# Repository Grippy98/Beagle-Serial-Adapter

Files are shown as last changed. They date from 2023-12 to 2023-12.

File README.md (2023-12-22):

# Beagle-Serial-Adapter
A CH340E Based Minimalist USB-Serial Adapter for BeaglePlay, AI64 and More.

The board is 4 layers and features components mainly sourced from LCSC for cost effectiveness and ease of building via JLC PCB or similar. 
It is designed in KiCAD 7.0.9.

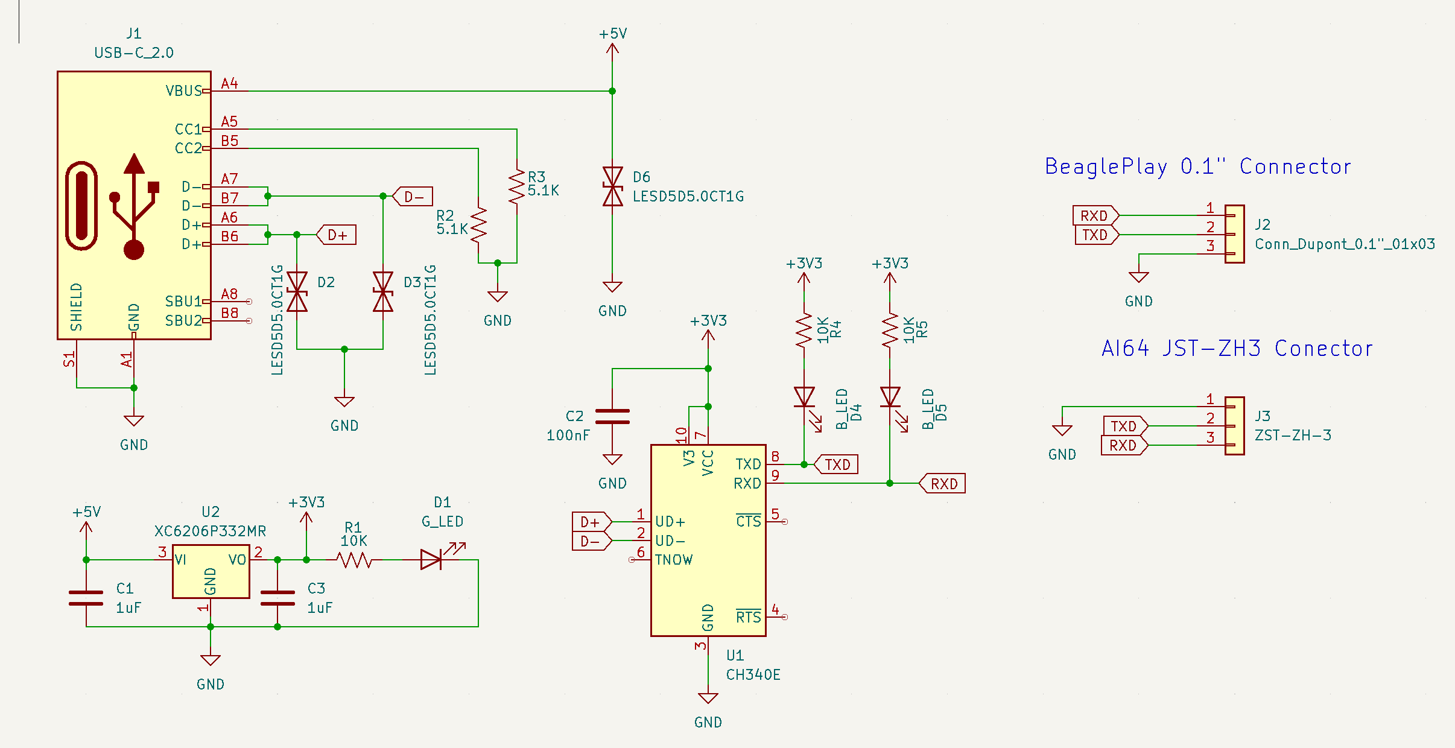
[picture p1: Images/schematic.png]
Schematic


Front           |  Back
:-------------------------:|:-------------------------:
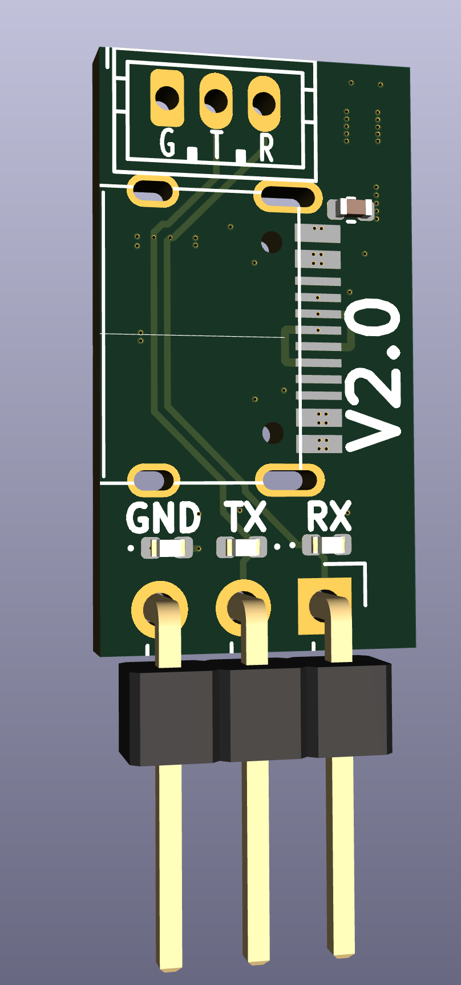
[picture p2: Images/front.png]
Front
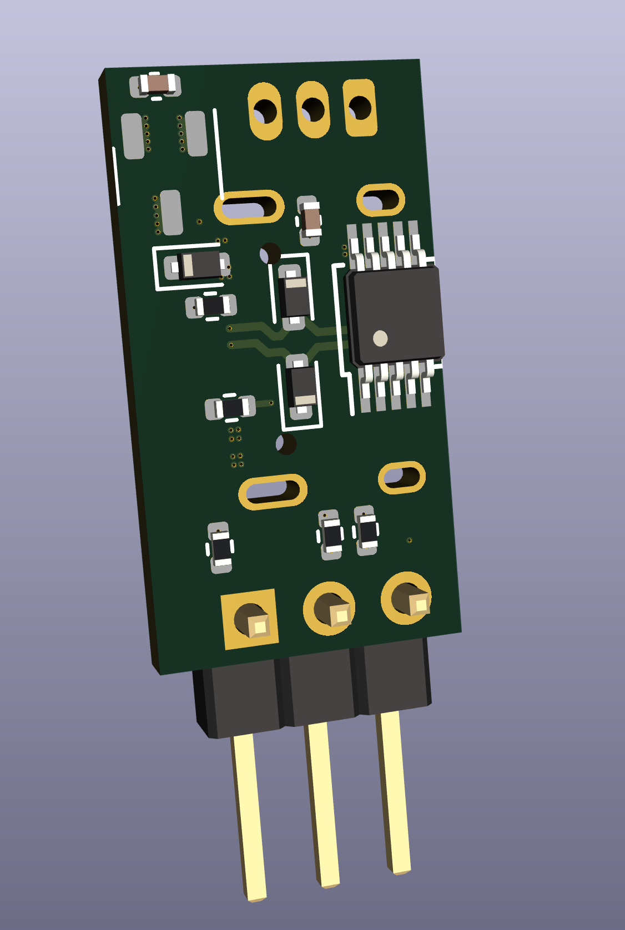
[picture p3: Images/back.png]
Back
  |  

> [!NOTE]  
> The header at the bottom should be Female to mate with BeaglePlay, not male as shown in the 3D render.

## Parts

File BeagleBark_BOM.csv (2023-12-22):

Id | Designator | Footprint | Quantity | Designation | Supplier and ref
1 | J3 | JST_ZH_B3B-ZR_1x03_P1.50mm_Vertical | 1 | ZST-ZH-3
2 | D1 | LED_0402_1005Metric | 1 | G_LED
3 | J2 | PinHeader_1x03_P2.54mm_Horizontal | 1 | Conn_Dupont_0.1_01x03"
4 | J1 | TYPE-C-31-M-12 | 1 | USB-C_2.0
5 | D5,D4 | LED_0402_1005Metric | 2 | B_LED
6 | C1,C3 | C_0402_1005Metric | 2 | 1uF
7 | U2 | SOT-23-3 | 1 | XC6206P332MR
8 | R2,R3 | R_0402_1005Metric | 2 | 5.1K
9 | R5,R4,R1 | R_0402_1005Metric | 3 | 10K
10 | D3,D2,D6 | D_SOD-523 | 3 | LESD5D5.0CT1G
11 | U1 | MSOP-10_3x3mm_P0.5mm | 1 | CH340E
12 | C2 | C_0402_1005Metric | 1 | 100nF

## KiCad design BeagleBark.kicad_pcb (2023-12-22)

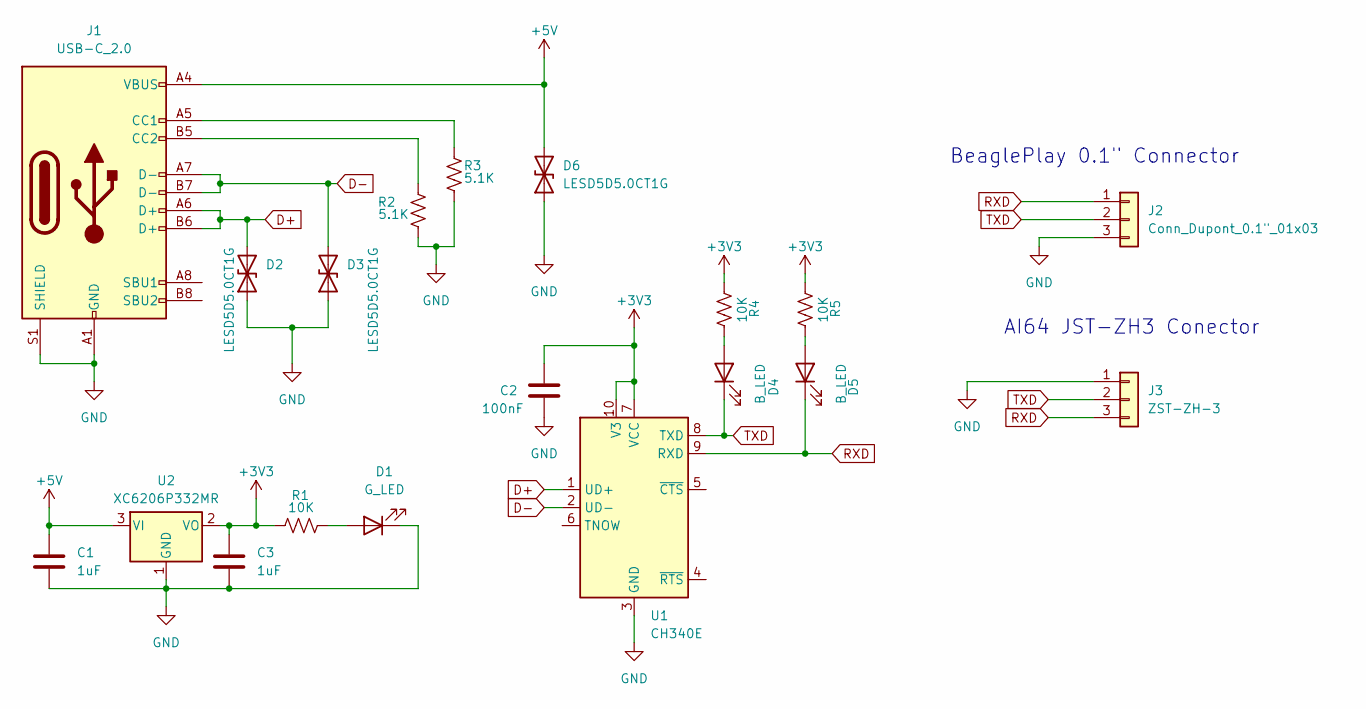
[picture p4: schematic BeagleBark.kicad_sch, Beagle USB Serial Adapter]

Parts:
C1, C3: 1uF; C_0402_1005Metric
C2: 100nF; C_0402_1005Metric
D1: G_LED; LED_0402_1005Metric
D2, D3, D6: LESD5D5.0CT1G; D_SOD-523
D4, D5: B_LED; LED_0402_1005Metric
J1: USB-C_2.0; TYPE-C-31-M-12
J2: Conn_Dupont_0.1"_01x03; PinHeader_1x03_P2.54mm_Horizontal
J3: ZST-ZH-3; JST_ZH_B3B-ZR_1x03_P1.50mm_Vertical
R1, R4, R5: 10K; R_0402_1005Metric
R2, R3: 5.1K; R_0402_1005Metric
U1: CH340E; MSOP-10_3x3mm_P0.5mm
U2: XC6206P332MR; SOT-23-3

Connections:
+3V3: C2.1, C3.1, R1.1, R4.1, R5.1, U1.7 (VCC), U1.10 (V3), U2.2 (VO)
+5V: C1.1, D6.2 (A2), J1.A4 (VBUS), J1.A9 (VBUS), J1.B4 (VBUS), J1.B9 (VBUS), U2.3 (VI)
D+: D2.2 (A2), J1.A6 (D+), J1.B6 (D+), U1.1 (UD+)
D-: D3.2 (A2), J1.A7 (D-), J1.B7 (D-), U1.2 (UD-)
GND: C1.2, C2.2, C3.2, D1.1 (K), D2.1 (A1), D3.1 (A1), D6.1 (A1), J1.A1 (GND), J1.A12 (GND), J1.B1 (GND), J1.B12 (GND), J1.S1 (SHIELD), J2.3, J3.1, R2.2, R3.2, U1.3 (GND), U2.1 (GND)
unnamed: D1.2 (A), R1.2
unnamed: D4.2 (A), R4.2
unnamed: D5.2 (A), R5.2
unnamed: J1.A5 (CC1), R3.1
unnamed: J1.B5 (CC2), R2.1
RXD: D5.1 (K), J2.1, J3.3, U1.9 (RXD)
TXD: D4.1 (K), J2.2, J3.2, U1.8 (TXD)

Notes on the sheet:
AI64 JST-ZH3 Conector
BeaglePlay 0.1" Connector

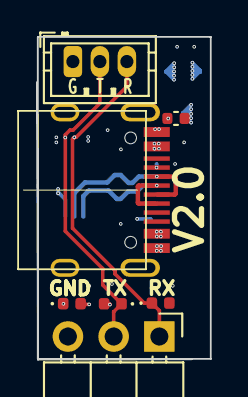
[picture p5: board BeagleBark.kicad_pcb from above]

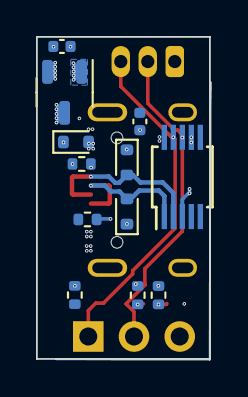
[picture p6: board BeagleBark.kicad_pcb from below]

Board: 4 copper layers, 9.6 x 17.9 mm, 19 parts (12 on the bottom side), 12 nets.
